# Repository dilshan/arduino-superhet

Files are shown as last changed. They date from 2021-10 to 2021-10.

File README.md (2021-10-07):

# Arduino Superheterodyne Receiver

In this project, we will upgrade a traditional shortwave [superheterodyne receiver](http://jayakody2000lk.blogspot.com/2015/03/two-transistor-superheterodyne.html) with an *[Arduino](https://store.arduino.cc/products/arduino-uno-rev3)* base tuner. This tuner is capable of receiving shortwave broadcasts on 41m band and above.

In this upgrade, we enhanced the local oscillator with [Si5351 clock generator module](https://s.click.aliexpress.com/e/_9iD0bV) and Arduino control circuit. Compared to the [old design](http://jayakody2000lk.blogspot.com/2015/03/two-transistor-superheterodyne.html), this new receiver uses an improved version of an intermediate frequency amplifier with 3 I.F transformers.

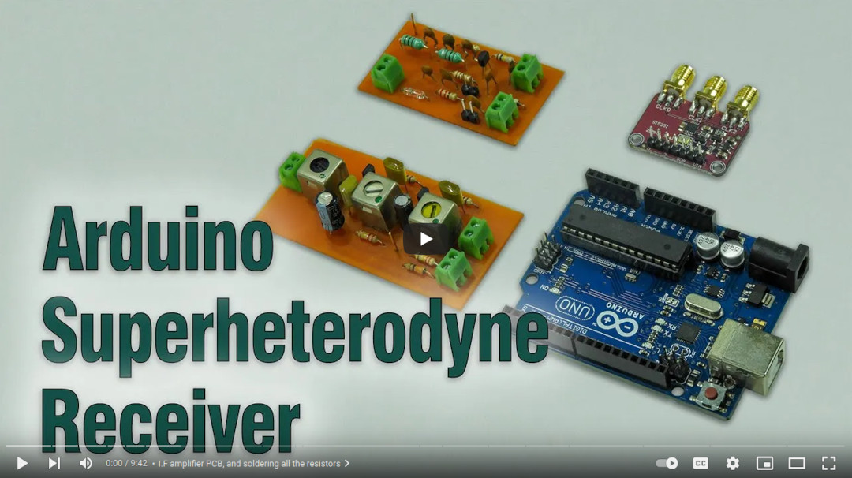
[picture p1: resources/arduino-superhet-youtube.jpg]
Arduino Superheterodyne Receiver (https://www.youtube.com/watch?v=8Wvycy0YoPc)


In this new design, we divide this receiver into several blocks, which include, mixer with a detector, a local oscillator, and an I.F amplifier. The I.F amplifier builds into one PCB. The filter stage, mixer, and detector stages place in another PCB.

In this prototype build, the *Si5351* clock generator drives using an *Arduino Uno* board. With the given sketch, the user can tune and switch the shortwave meter bands using a rotary encoder. The supplied sketch support clock generation from 5205kHz (tuner frequency : 4750kHz) to 16285kHz (tuner frequency : 15830kHz). If required, this range can further extend or reduce by modifying the Arduino source code. In the given source code, we use [*Etherkit's Si5351 library*](https://github.com/etherkit/Si5351Arduino) to control the clock generator module.

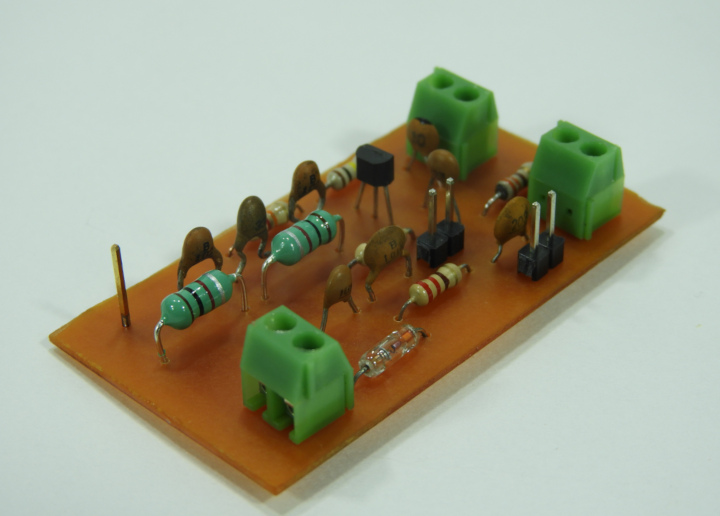
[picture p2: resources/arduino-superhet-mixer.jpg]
Prototype version of the filter, mixer and detector PCB.


This receiver uses a conventional 455kHz I.F transformer kit in an intermediate frequency amplifier. We use a [2SC724](https://www.web-bcs.com/transistor/tc/2sc/2SC724.php) transistor for each filter stage. The value of this transistor is not critical and can be replaced with any suitable mid-frequency NPN transistor, for example, [2SC930](https://s.click.aliexpress.com/e/_9vi1D5), [BF494](https://s.click.aliexpress.com/e/_Ap8gur), [BC337](https://s.click.aliexpress.com/e/_9gRclD), or [2SC829](https://s.click.aliexpress.com/e/_ACedU7), etc.

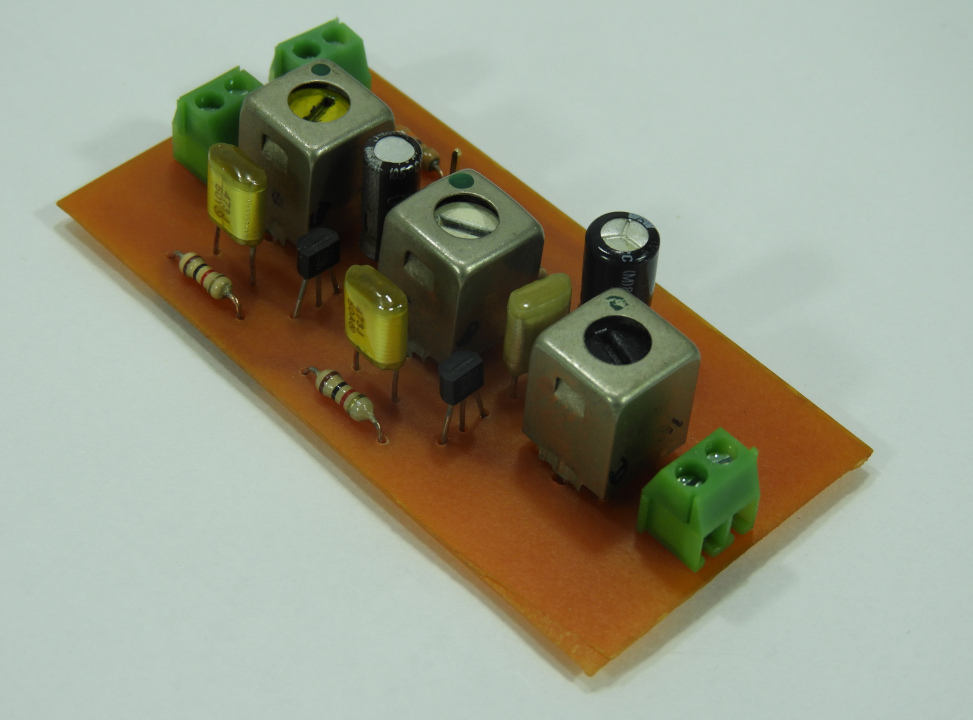
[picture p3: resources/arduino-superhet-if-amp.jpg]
Prototype version of I.F amplifier.


The 2nd PCB consists of a filter, mixer, and detector circuit. This mixer stage also uses the NPN low power transistor and can replace with any of the above transistors. The crucial component of the detector phase is the [OA90](https://s.click.aliexpress.com/e/_AknfCT) or [1N34](https://s.click.aliexpress.com/e/_AdOUUn) Germanium diode. It can also change with any suitable Germanium signal diode. 

The front filter stage constructs using a pair of readymade [1µH inductors](https://s.click.aliexpress.com/e/_ApVWb9). The suggested supply voltage to this tuner is 6V to 9V. 

All the design files of this project were released under the [Creative Commons Attribution 4.0 International](https://creativecommons.org/licenses/by/4.0/) license. The Arduino sketch is released under the [MIT License](https://github.com/dilshan/arduino-superhet/blob/main/LICENSE).

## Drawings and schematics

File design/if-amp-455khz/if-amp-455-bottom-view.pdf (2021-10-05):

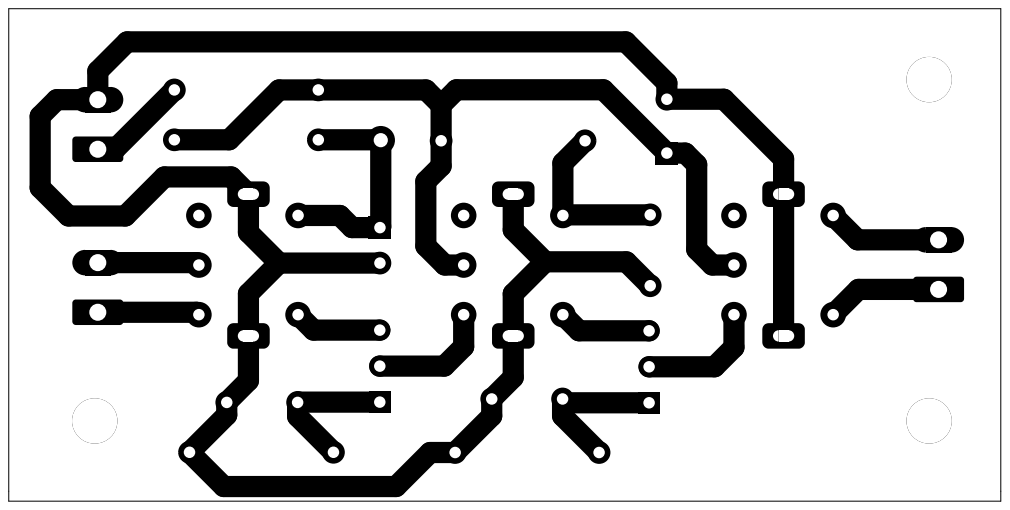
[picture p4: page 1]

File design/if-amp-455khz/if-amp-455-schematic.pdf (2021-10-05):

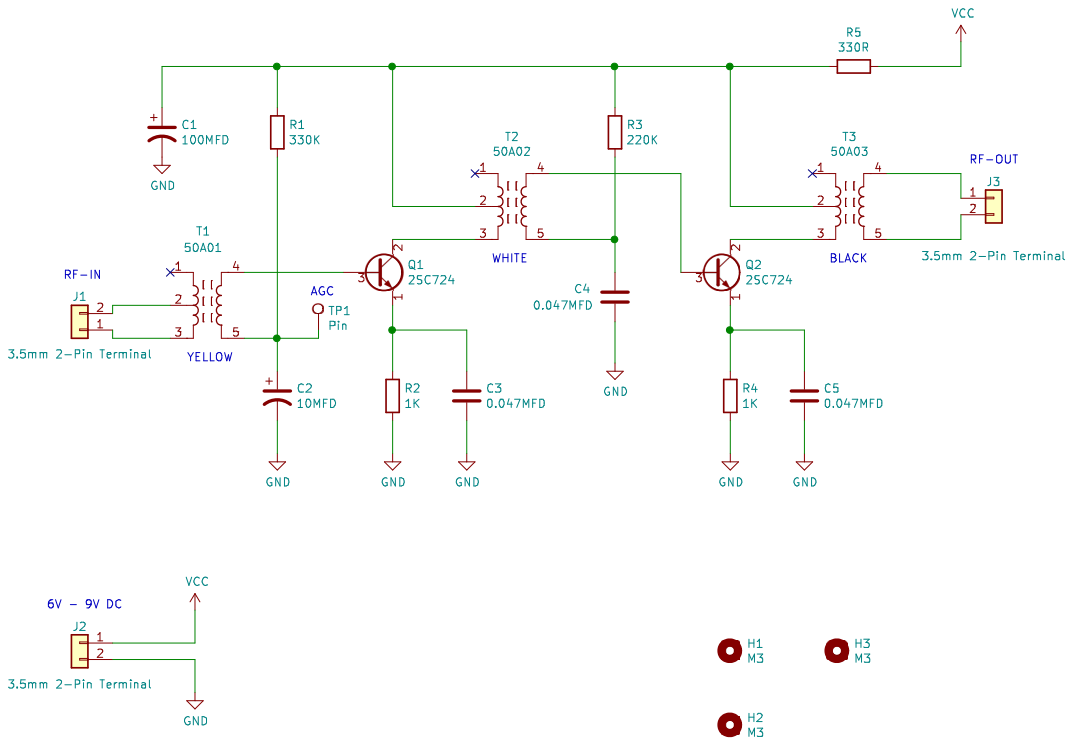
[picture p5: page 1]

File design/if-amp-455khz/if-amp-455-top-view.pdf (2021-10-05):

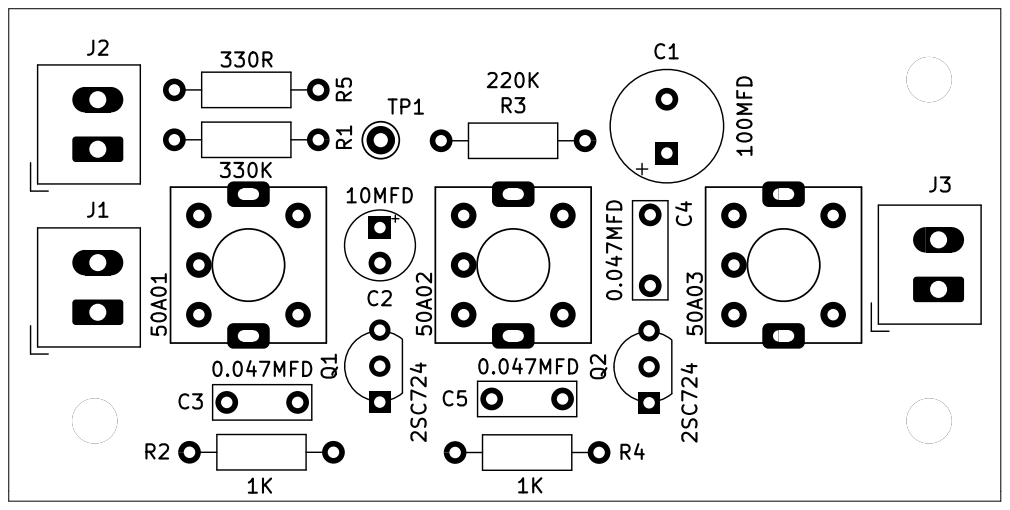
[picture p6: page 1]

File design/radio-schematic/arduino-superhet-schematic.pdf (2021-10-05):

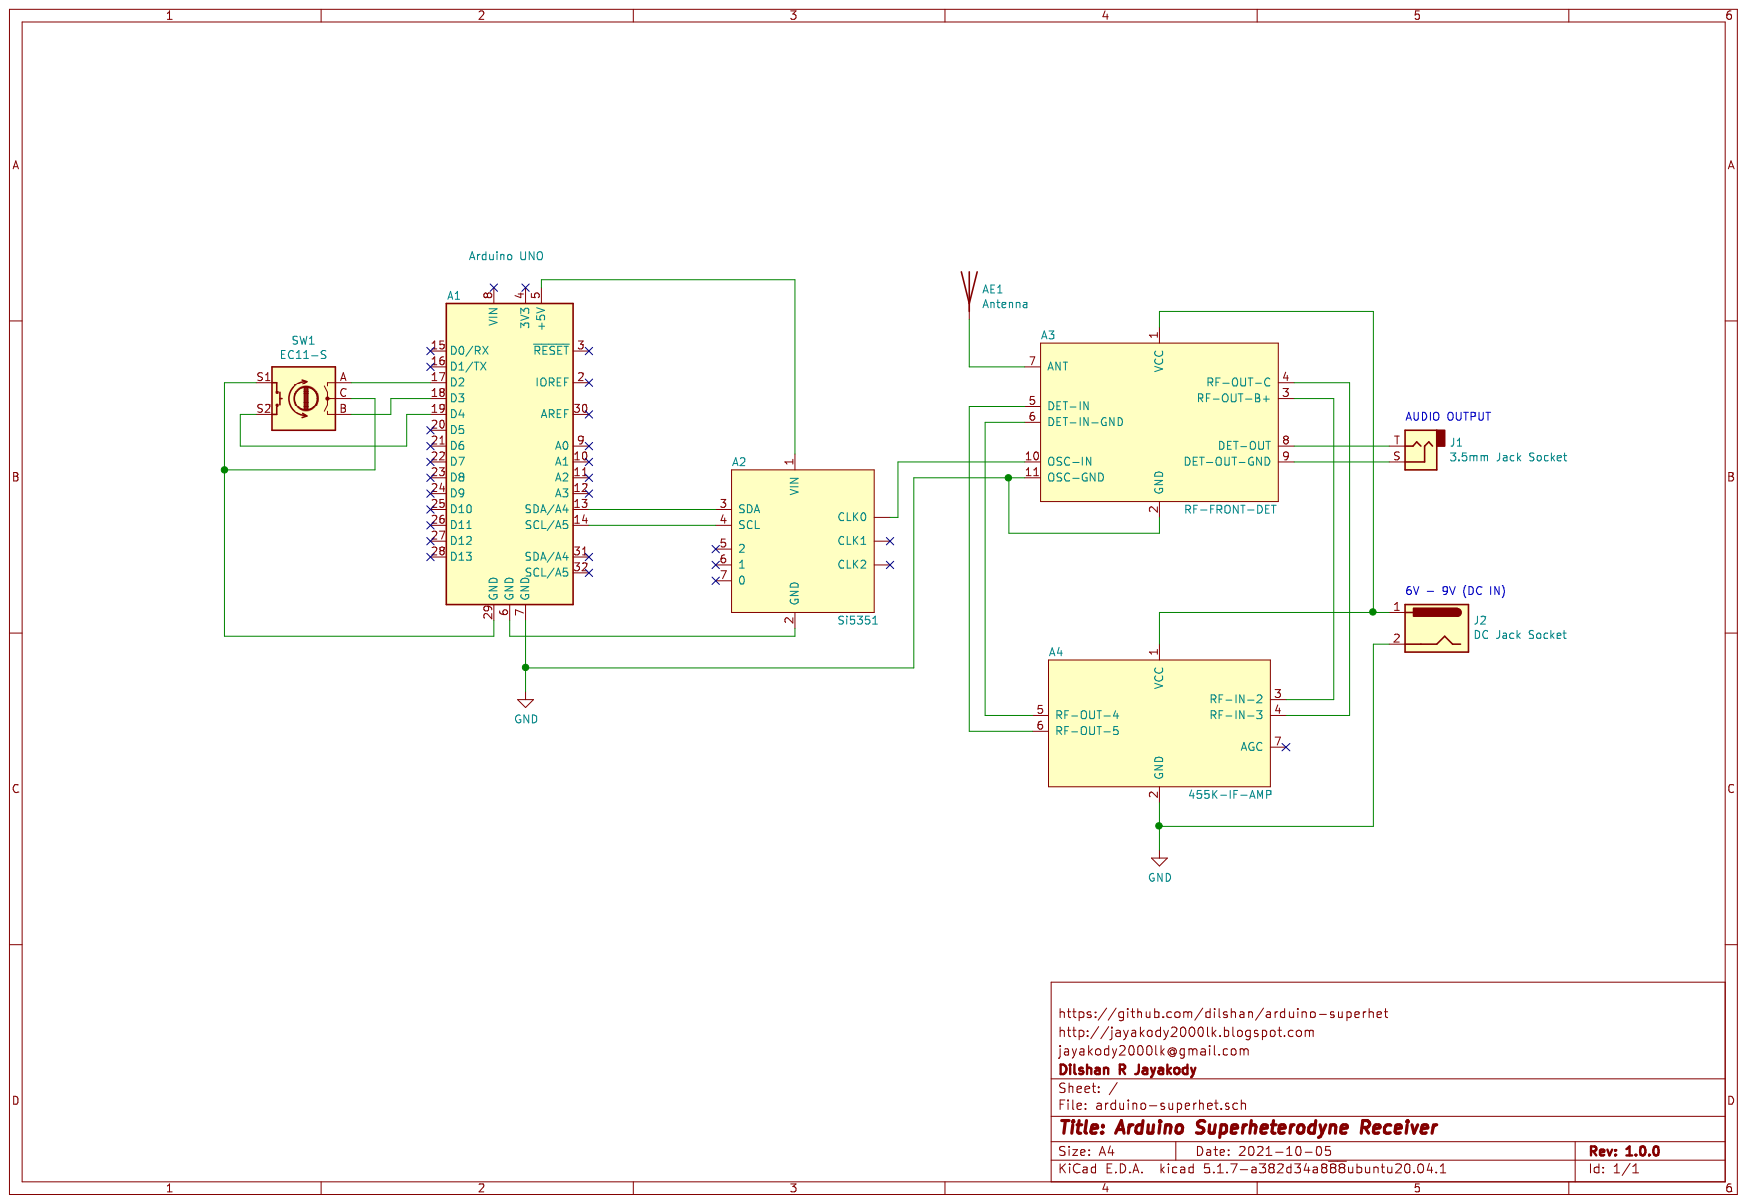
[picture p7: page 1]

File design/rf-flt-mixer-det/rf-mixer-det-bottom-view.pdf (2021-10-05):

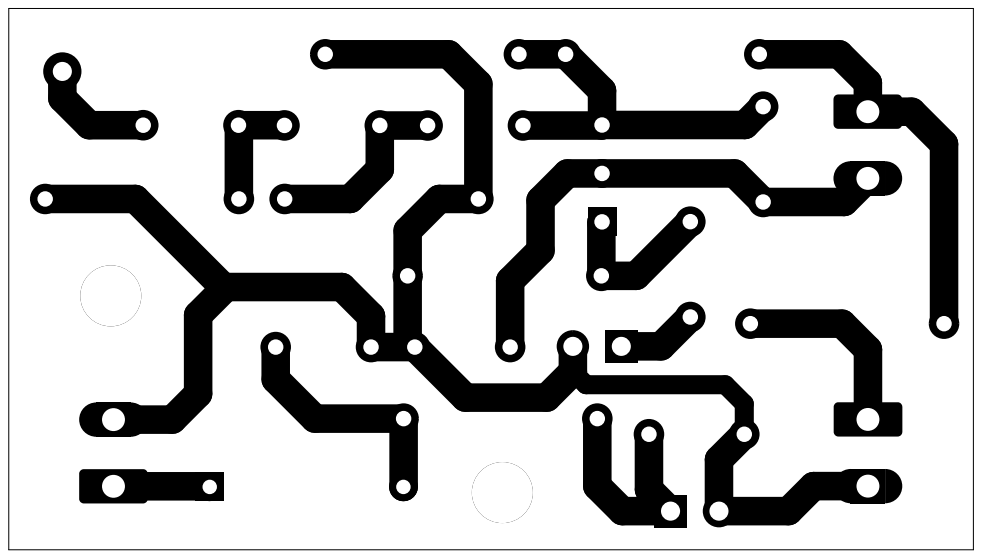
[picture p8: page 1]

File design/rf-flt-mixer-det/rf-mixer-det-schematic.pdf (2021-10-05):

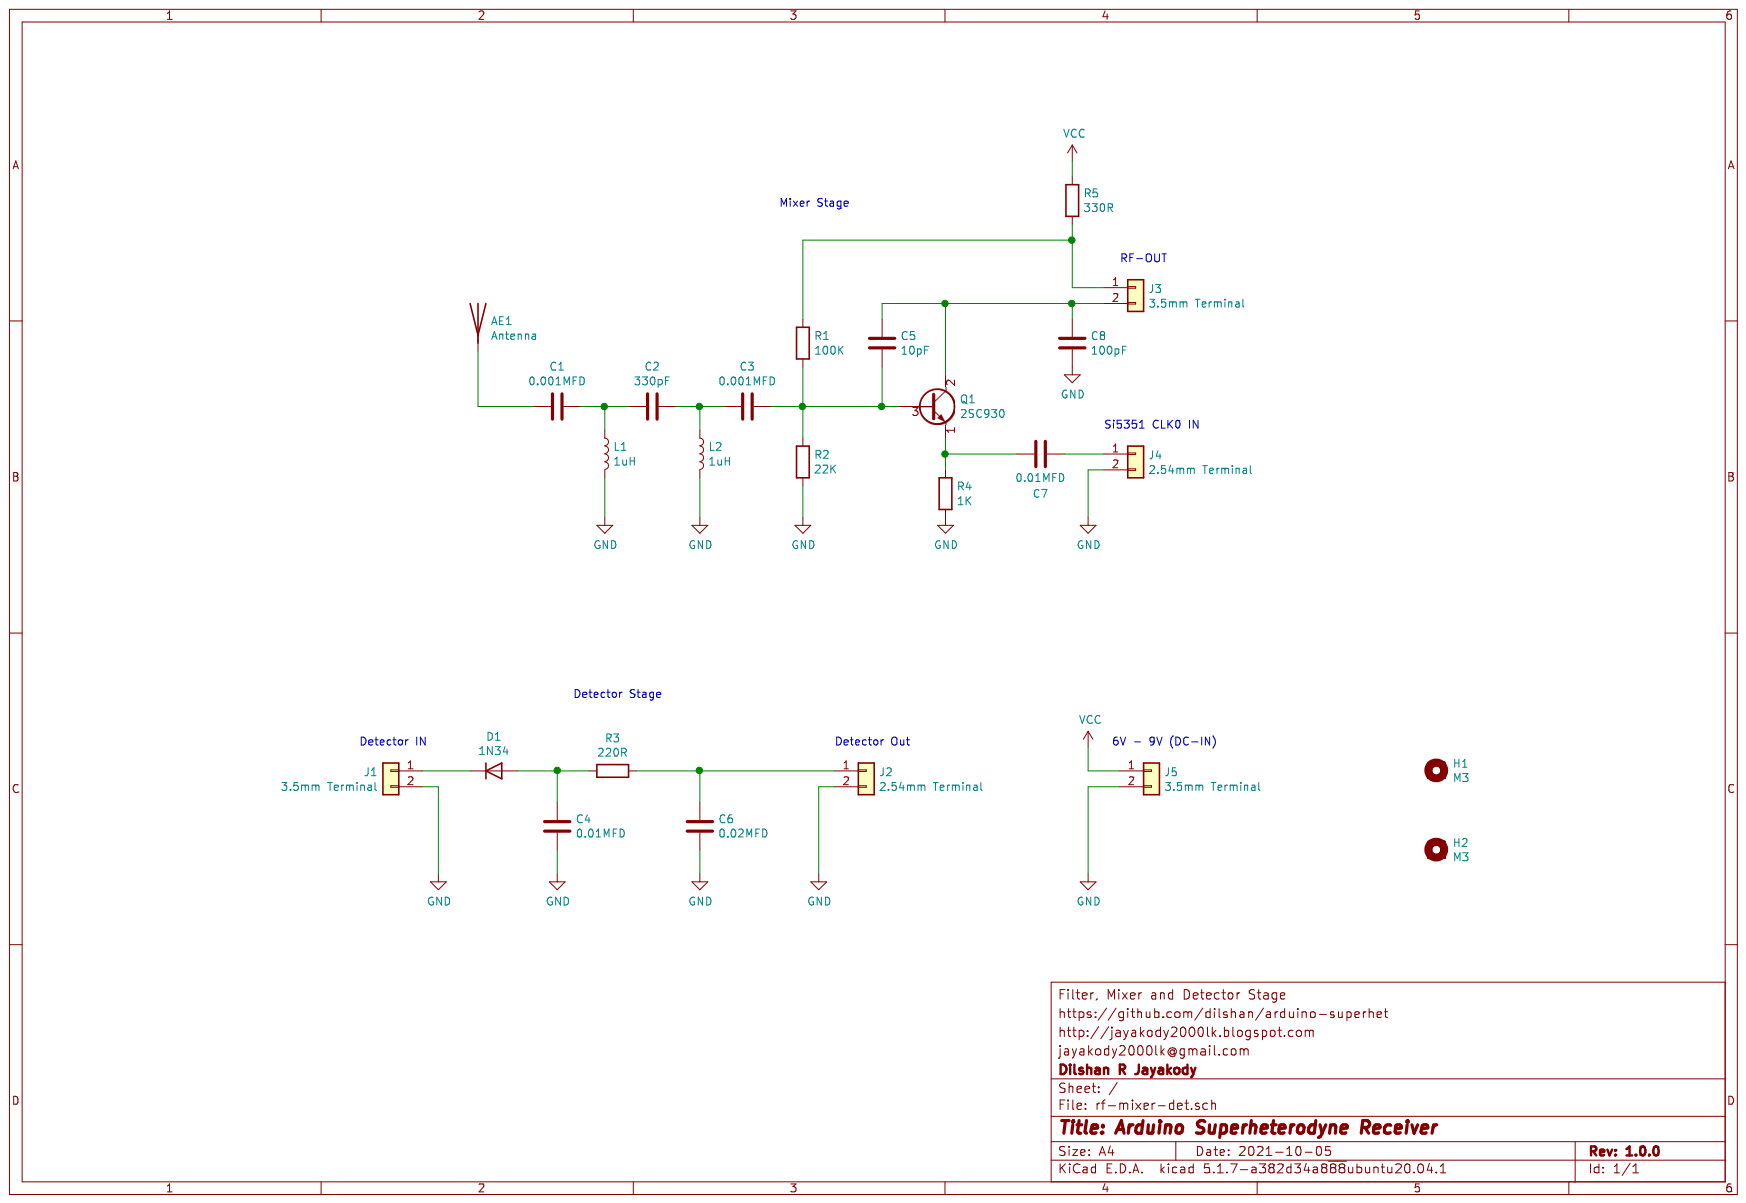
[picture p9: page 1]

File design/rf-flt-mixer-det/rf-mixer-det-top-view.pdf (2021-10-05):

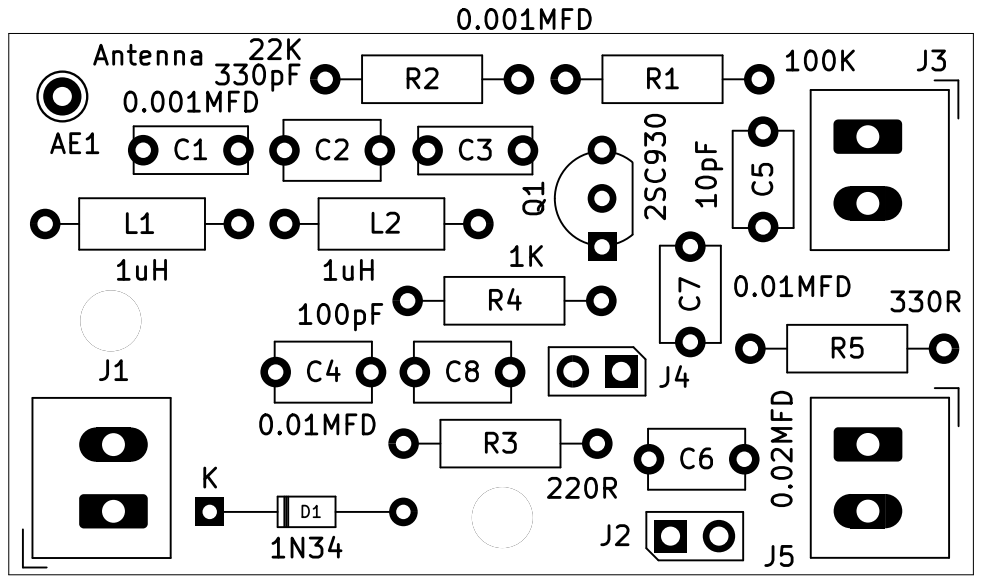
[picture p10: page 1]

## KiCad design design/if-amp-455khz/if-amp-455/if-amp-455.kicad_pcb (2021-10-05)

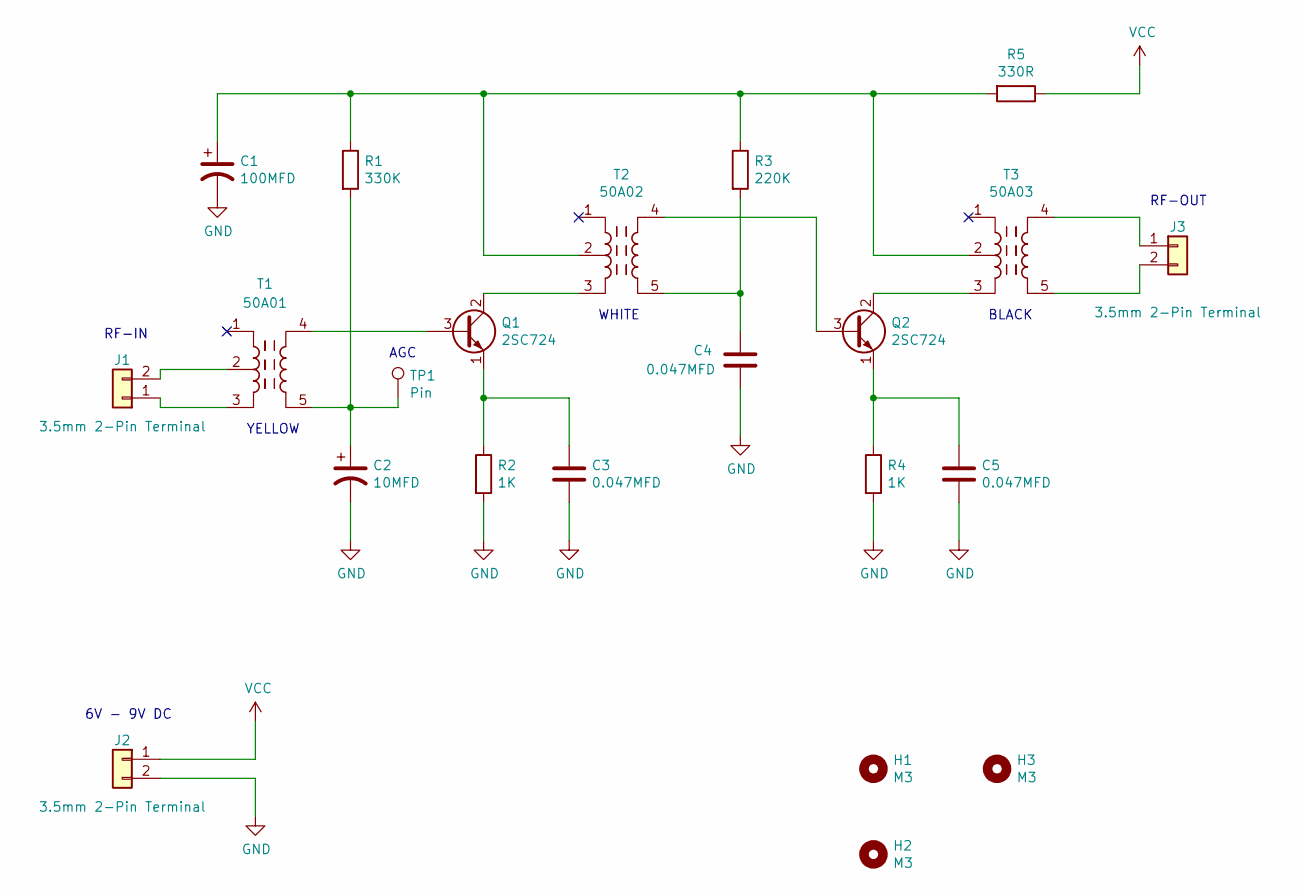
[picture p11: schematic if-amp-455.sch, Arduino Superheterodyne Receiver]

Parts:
C1: 100MFD; CP_Radial_D8.0mm_P3.80mm
C2: 10MFD; CP_Radial_D5.0mm_P2.50mm
C3, C4, C5: 0.047MFD; C_Disc_D7.0mm_W2.5mm_P5.00mm
H1, H2, H3: M3; MountingHole_3.2mm_M3
J1, J2, J3: 3.5mm 2-Pin Terminal; PhoenixContact_MCV_1,5_2-G-3.5_1x02_P3.50mm_Vertical
Q1, Q2: 2SC724; TO-92L_Inline_Wide
R1: 330K; R_Axial_DIN0207_L6.3mm_D2.5mm_P10.16mm_Horizontal
R2, R4: 1K; R_Axial_DIN0207_L6.3mm_D2.5mm_P10.16mm_Horizontal
R3: 220K; R_Axial_DIN0207_L6.3mm_D2.5mm_P10.16mm_Horizontal
R5: 330R; R_Axial_DIN0207_L6.3mm_D2.5mm_P10.16mm_Horizontal
T1: 50A01; 5-pin-if-transformer
T2: 50A02; 5-pin-if-transformer
T3: 50A03; 5-pin-if-transformer
TP1: Pin; TestPoint_Loop_D1.80mm_Drill1.0mm_Beaded

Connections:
GND: C1.2, C2.2, C3.2, C4.2, C5.2, J2.2, R2.2, R4.2, T1.6, T2.6, T3.6
unnamed: C1.1, R1.1, R3.1, R5.2, T2.2, T3.2
unnamed: C2.1, R1.2, T1.5, TP1.1
unnamed: C3.1, Q1.1 (E), R2.1
unnamed: C4.1, R3.2, T2.5
unnamed: C5.1, Q2.1 (E), R4.1
unnamed: J1.1, T1.3
unnamed: J1.2, T1.2
unnamed: J3.1, T3.4
unnamed: J3.2, T3.5
unnamed: Q1.2 (C), T2.3
unnamed: Q1.3 (B), T1.4
unnamed: Q2.2 (C), T3.3
unnamed: Q2.3 (B), T2.4
VCC: J2.1, R5.1

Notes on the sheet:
YELLOW
WHITE
BLACK
AGC
6V - 9V DC
RF-IN
RF-OUT

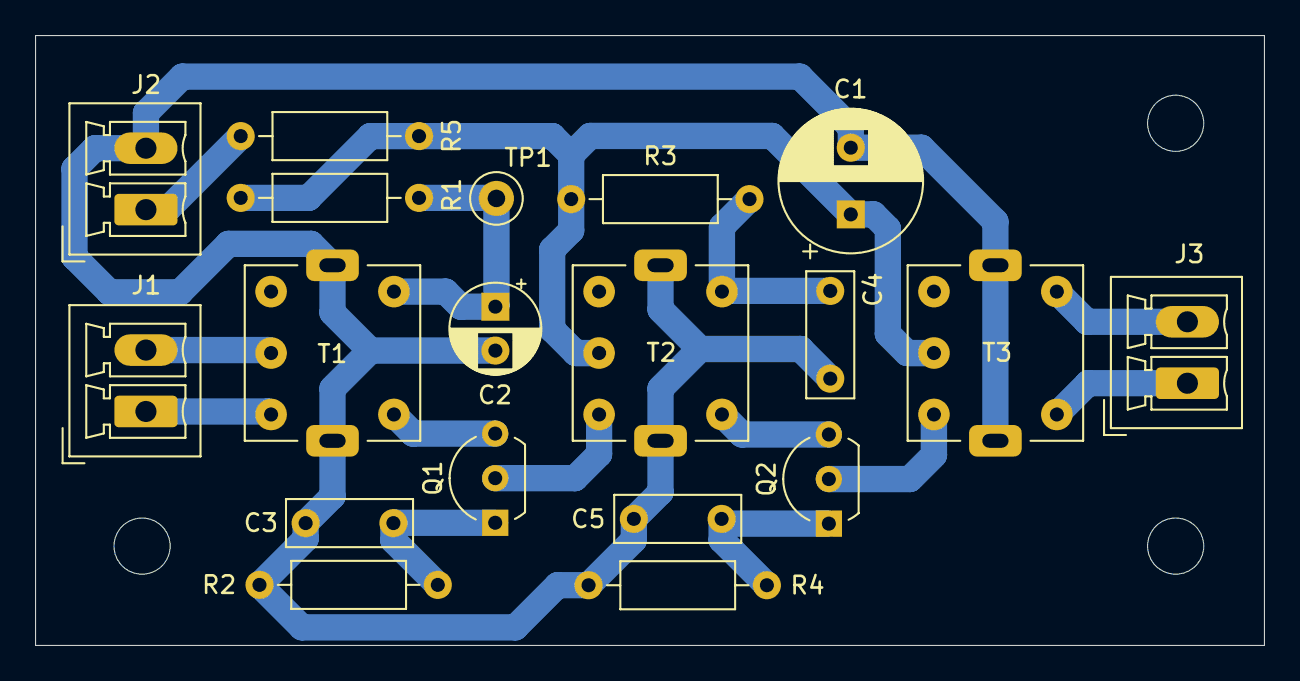
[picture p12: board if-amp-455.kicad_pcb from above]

Board: 2 copper layers, 70.0 x 34.8 mm, 22 parts (0 on the bottom side), 15 nets.

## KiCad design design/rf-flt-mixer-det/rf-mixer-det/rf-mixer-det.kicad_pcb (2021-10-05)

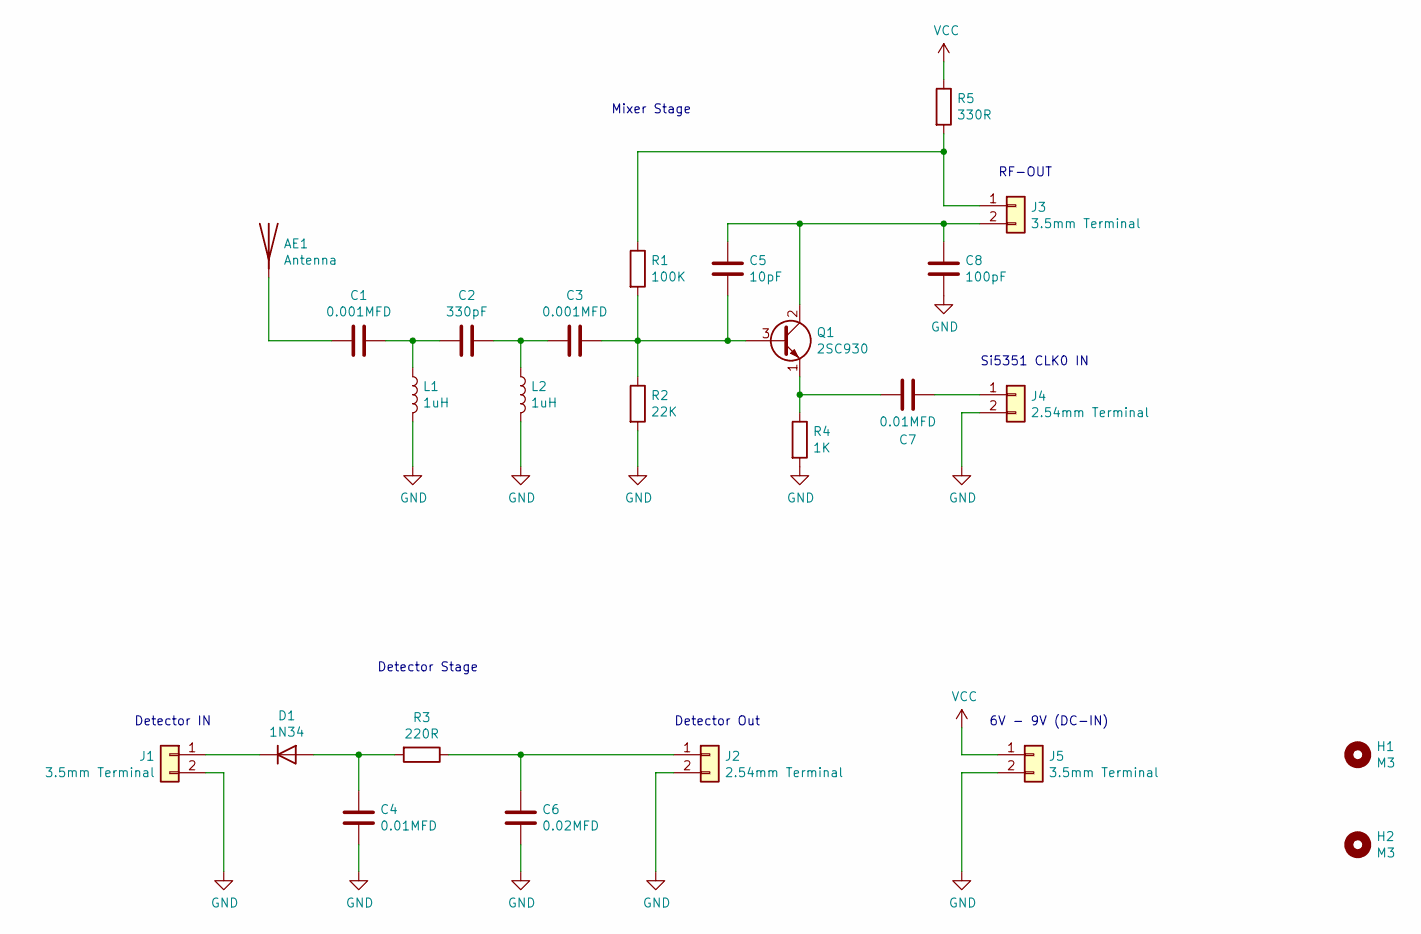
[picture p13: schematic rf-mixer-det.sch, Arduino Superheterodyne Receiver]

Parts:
AE1: Antenna; TestPoint_Loop_D1.80mm_Drill1.0mm_Beaded
C1, C3: 0.001MFD; C_Disc_D6.0mm_W2.5mm_P5.00mm
C2: 330pF; C_Disc_D5.1mm_W3.2mm_P5.00mm
C4, C7: 0.01MFD; C_Disc_D5.1mm_W3.2mm_P5.00mm
C5: 10pF; C_Disc_D5.1mm_W3.2mm_P5.00mm
C6: 0.02MFD; C_Disc_D5.1mm_W3.2mm_P5.00mm
C8: 100pF; C_Disc_D5.1mm_W3.2mm_P5.00mm
D1: 1N34; D_DO-34_SOD68_P10.16mm_Horizontal
H1, H2: M3; MountingHole_3.2mm_M3
J1, J3, J5: 3.5mm Terminal; PhoenixContact_MCV_1,5_2-G-3.5_1x02_P3.50mm_Vertical
J2, J4: 2.54mm Terminal; PinHeader_1x02_P2.54mm_Vertical
L1, L2: 1uH; L_Axial_L6.6mm_D2.7mm_P10.16mm_Horizontal_Vishay_IM-2
Q1: 2SC930; TO-92L_Inline_Wide
R1: 100K; R_Axial_DIN0207_L6.3mm_D2.5mm_P10.16mm_Horizontal
R2: 22K; R_Axial_DIN0207_L6.3mm_D2.5mm_P10.16mm_Horizontal
R3: 220R; R_Axial_DIN0207_L6.3mm_D2.5mm_P10.16mm_Horizontal
R4: 1K; R_Axial_DIN0207_L6.3mm_D2.5mm_P10.16mm_Horizontal
R5: 330R; R_Axial_DIN0207_L6.3mm_D2.5mm_P10.16mm_Horizontal

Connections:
GND: C4.2, C6.2, C8.2, J1.2, J2.2, J4.2, J5.2, L1.2, L2.2, R2.2, R4.2
unnamed: AE1.1, C1.2
unnamed: C1.1, C2.2, L1.1
unnamed: C2.1, C3.2, L2.1
unnamed: C3.1, C5.2, Q1.3 (B), R1.2, R2.1
unnamed: C4.1, D1.2 (A), R3.2
unnamed: C5.1, C8.1, J3.2, Q1.2 (C)
unnamed: C6.1, J2.1, R3.1
unnamed: C7.1, J4.1
unnamed: C7.2, Q1.1 (E), R4.1
unnamed: D1.1 (K), J1.1
unnamed: J3.1, R1.1, R5.2
VCC: J5.1, R5.1

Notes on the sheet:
Detector Stage
Mixer Stage
Detector IN
Detector Out
6V - 9V (DC-IN)
Si5351 CLK0 IN
RF-OUT

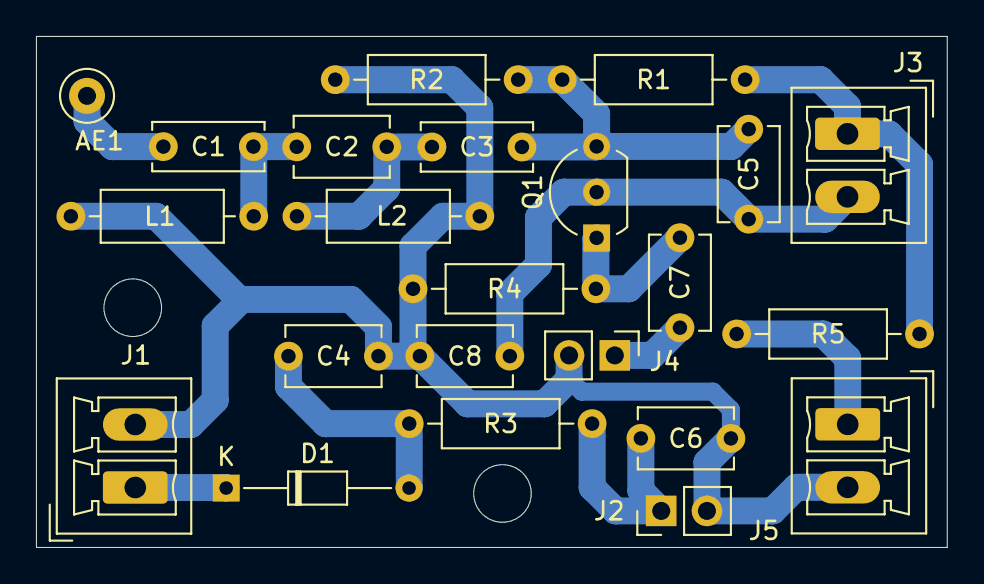
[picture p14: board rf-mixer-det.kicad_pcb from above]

Board: 2 copper layers, 50.6 x 28.4 mm, 25 parts (0 on the bottom side), 13 nets.

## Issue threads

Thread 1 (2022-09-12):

Filter out second RF

kirushyk, 2022-09-12:
As I know, when mixing RF with local oscillator, your mixer input tunes to two radio frequencies. But it looks like you only use high pass filter after antenna, so probably you need to somehow filter out mirror frequency?

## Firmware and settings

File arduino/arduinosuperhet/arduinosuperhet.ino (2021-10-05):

/*********************************************************************************
Copyright (c) 2021 Dilshan R Jayakody.

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
THE SOFTWARE IS PROVIDED "AS IS", WITHOUT WARRANTY OF ANY KIND, EXPRESS OR
IMPLIED, INCLUDING BUT NOT LIMITED TO THE WARRANTIES OF MERCHANTABILITY,
FITNESS FOR A PARTICULAR PURPOSE AND NONINFRINGEMENT. IN NO EVENT SHALL THE
AUTHORS OR COPYRIGHT HOLDERS BE LIABLE FOR ANY CLAIM, DAMAGES OR OTHER
LIABILITY, WHETHER IN AN ACTION OF CONTRACT, TORT OR OTHERWISE, ARISING FROM,
OUT OF OR IN CONNECTION WITH THE SOFTWARE OR THE USE OR OTHER DEALINGS IN THE
SOFTWARE.
*********************************************************************************/

#include "Si5351Arduino/src/si5351.h"

#define ROTARY_ENCODER_PIN_1      2
#define ROTARY_ENCODER_PIN_2      3
#define ROTARY_ENCODER_BUTTON_PIN 4

#define RECEIVER_START_FREQUENCY  700000000ULL
#define INTERMEDIATE_FREQUENCY    45500000ULL
#define STEP_FREQUENCY            100000ULL

#define TUNER_LOW_FREQUENCY       475000000ULL
#define TUNER_HIGH_FREQUENCY      1583000000ULL

typedef enum tunerDirection
{
  TUNERDIR_IDLE,
  TUNERDIR_UP,
  TUNERDIR_DOWN
} tunerDirection;

tunerDirection tunerState;
Si5351 si5351;

unsigned long long freq = RECEIVER_START_FREQUENCY;
unsigned char buttonState;
char printBuffer[50];

void updateTunerFrequency()
{
  // Update CLK0 output frequency.
  si5351.set_freq(freq + INTERMEDIATE_FREQUENCY, SI5351_CLK0);

  // Print current frequency on serial console.
  sprintf(printBuffer, "%ld", (unsigned long long)freq);
  Serial.println(printBuffer);
}

void setup()
{
  bool si5351Status;
  tunerState = TUNERDIR_IDLE;

  // Initialize UART with baud rate of 57600 with 8N1 configuration.
  Serial.begin(57600);

  // Configure rotary encorder pins and ISR.
  pinMode(ROTARY_ENCODER_PIN_1, INPUT_PULLUP);
  pinMode(ROTARY_ENCODER_PIN_2, INPUT_PULLUP);
  pinMode(ROTARY_ENCODER_BUTTON_PIN, INPUT_PULLUP);
  attachInterrupt(0, onChangeISR, CHANGE);

  // Initialize Si5351 module as local oscillator.
  si5351Status = si5351.init(SI5351_CRYSTAL_LOAD_8PF, 0, 0);
  if(!si5351Status)
  {
    Serial.println("SI5351 module is not attached to the Arduino!");
  }  

  delay(100);

  // Enable local oscillator on CLK0.
  updateTunerFrequency();  

  // Get rotary encoder button state.
  buttonState = digitalRead(ROTARY_ENCODER_BUTTON_PIN);
}

void loop() 
{
  // Rotary encoder rotation related updates.
  if(tunerState == TUNERDIR_UP)
  {
    // Increase tuner frequency within the specified frequency range.
    if(freq < TUNER_HIGH_FREQUENCY)
    {
      freq += STEP_FREQUENCY;
      updateTunerFrequency();
    }
  }
  else if(tunerState == TUNERDIR_DOWN)
  {
    // Decrease tuner frequency within the specified frequency range.
    if(freq > TUNER_LOW_FREQUENCY)
    {
      freq -= STEP_FREQUENCY;
      updateTunerFrequency();
    }
  }

  // Rotation encoder button press event.
  if((digitalRead(ROTARY_ENCODER_BUTTON_PIN) == HIGH) && (buttonState == LOW))
  {
    // switch to next available meter band (frequency range).
    if((freq <= 506000000ULL))
    {
      // 49m band.
      freq = 590000000ULL;
    }
    else if(freq <= 620000000ULL)
    {
      // 41m band.
      freq = 720000000ULL;
    }
    else if(freq <= 760000000ULL)
    {
      // 31m band.
      freq = 940000000ULL;
    }
    else if(freq <= 990000000ULL)
    {
      // 25m band.
      freq = 1160000000ULL;
    }
    else if(freq <= 1210000000ULL)
    {
      // 22m band.
      freq = 1357000000ULL;
    }
    else if(freq <= 1387000000ULL)
    {
      // 19m band.
      freq = 1510000000ULL;
    }
    else if(freq <= TUNER_HIGH_FREQUENCY)
    {
      // Reset to lowest meter band (60m).
      freq = TUNER_LOW_FREQUENCY;
    }

    // Tune local oscillator to the newest meter band.
    updateTunerFrequency();
  }

  buttonState = digitalRead(ROTARY_ENCODER_BUTTON_PIN);
  
  // Reset rotary encorder tuner state.
  tunerState = TUNERDIR_IDLE;
  delay(50);
}

void onChangeISR()
{
  // Handle rotary encorder up/down events.
  if(digitalRead(ROTARY_ENCODER_PIN_1) == digitalRead(ROTARY_ENCODER_PIN_2))
  {
    tunerState = TUNERDIR_UP;
  }
  else
  {
    tunerState = TUNERDIR_DOWN;
  }
}

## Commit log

2021-10-05 Initial version of source codes and design files.
    [arduino-superhet.sch, if-amp-455.kicad_pcb, if-amp-455.sch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]
2021-10-05 :art: Add images of the prototype builds.
2021-10-07 Create CI script for the Arduino sketch.
